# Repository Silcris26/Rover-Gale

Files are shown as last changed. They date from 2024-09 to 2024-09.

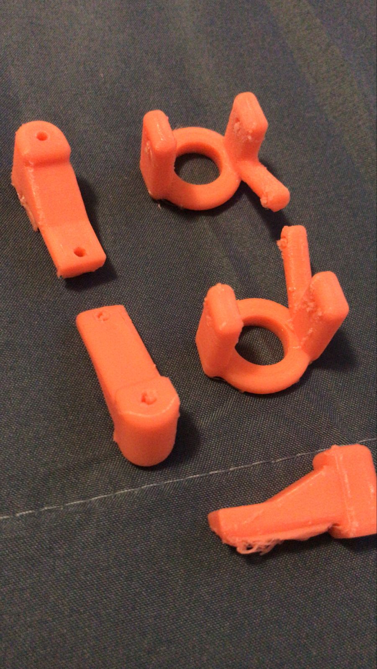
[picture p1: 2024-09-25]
Diseño 3D/6.jpg

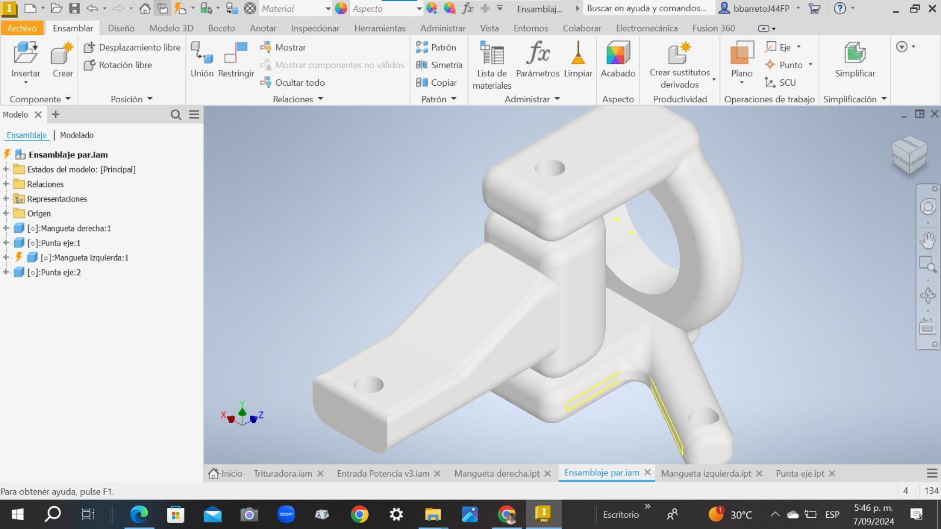
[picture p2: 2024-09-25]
Diseño 3D/3.jpg

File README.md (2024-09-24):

# Rover-Gale

A lo largo de los años, la exploración de Marte ha sido un desafío debido a las condiciones inhóspitas y la lejanía del planeta, las misiones tripuladas aún son extremadamente costosas y peligrosas, aún más cuando hablamos del análisis de la corteza marciana, lo que limita la capacidad de intervención humana para llevar a cabo investigaciones directas en su superficie. Esta problemática requiere de soluciones tecnológicas capaces de explorar, analizar y transmitir información desde Marte, la manera más práctica de hacerlo es a través de un Rover fácil de controlar y capaz de explorar el terreno hostil, lugares de complicado alcance y recorrer largas distancias. Se propone la implementación de motorreductores para las llantas traseras y un servomotor capaz de dar la dirección en las llantas delanteras con piezas impresas en 3D para su fácil replicación y reemplazo en caso de averías, su fuente de energía se da a través de baterías recargables lo cual no solo prolonga la vida útil del vehículo sino que también reduce significativamente la contaminación emitida, como resultado tenemos un Rover cuyas características le hacen eficiente, impulsando la comprensión científica y la preparación para misiones humanas en Marte, validado mediante pruebas hechas en terrenos similares.

Banner Envio Gratis Moderno Negro y Azul

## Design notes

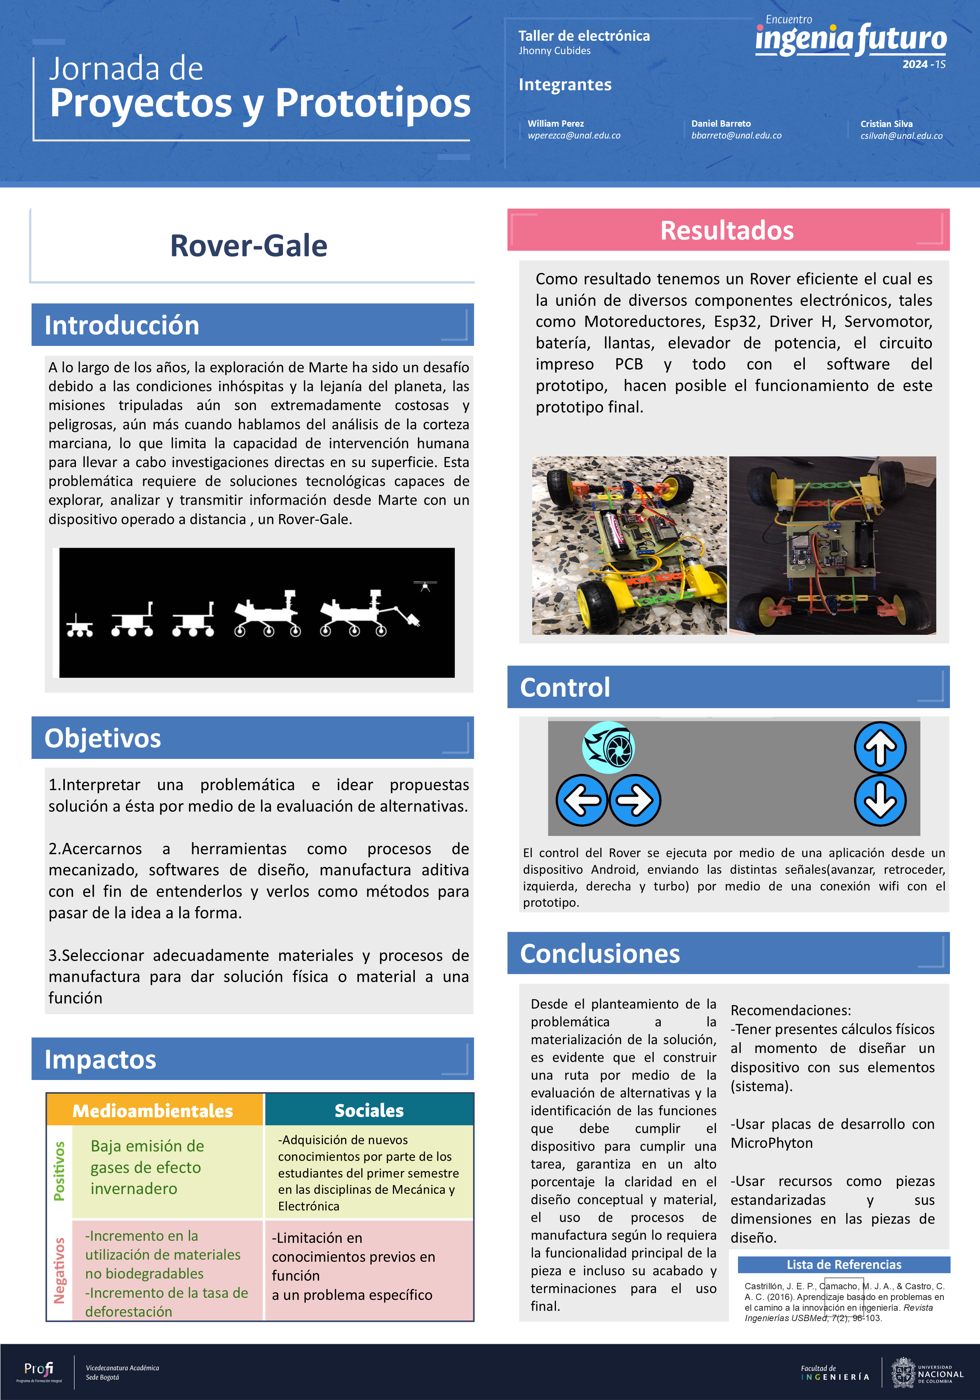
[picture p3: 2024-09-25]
Poster.png

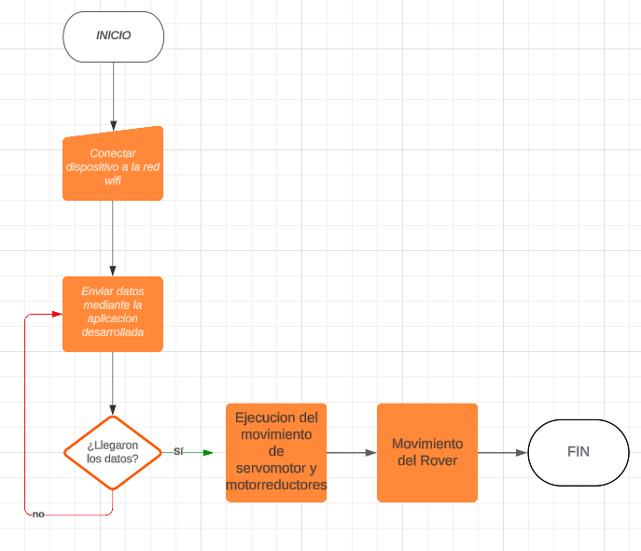
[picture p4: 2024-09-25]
Diagramas/Diagrama General.png

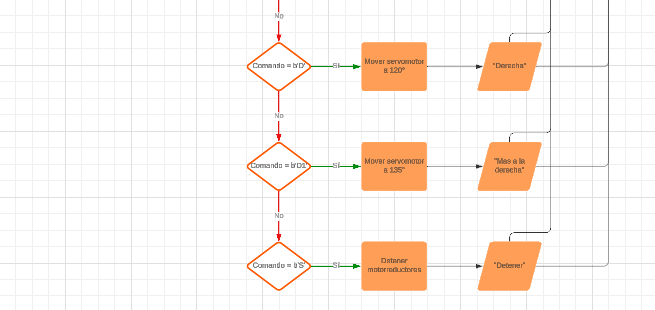
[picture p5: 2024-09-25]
Diagramas/SePartDiagrama.png

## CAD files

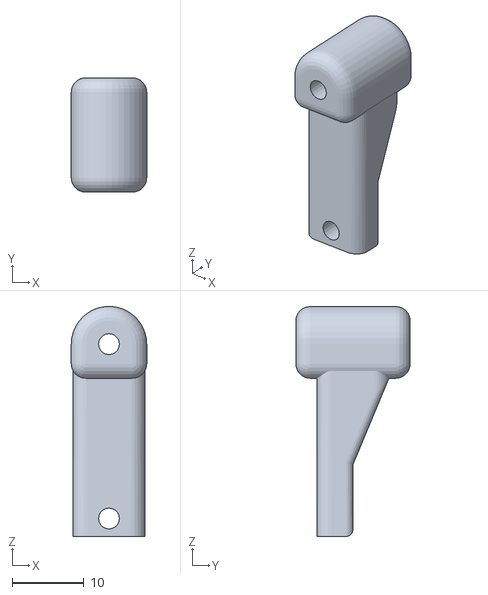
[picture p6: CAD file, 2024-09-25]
Diseño 3D/Punta eje.stl
10.5 x 15.9 x 32.0

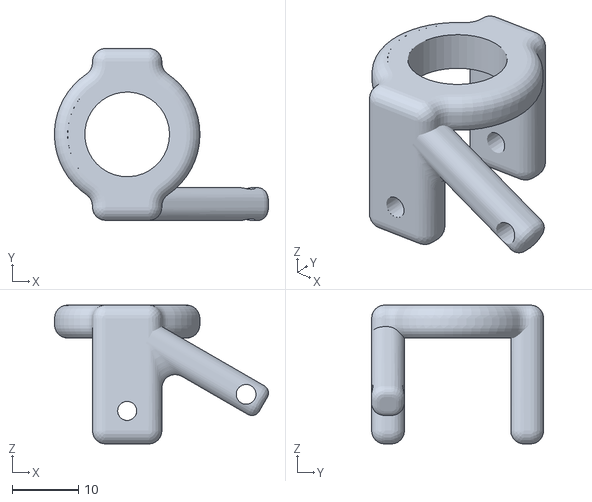
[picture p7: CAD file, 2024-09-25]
Diseño 3D/Mangueta izquierda.stl
32.3 x 26.0 x 21.0

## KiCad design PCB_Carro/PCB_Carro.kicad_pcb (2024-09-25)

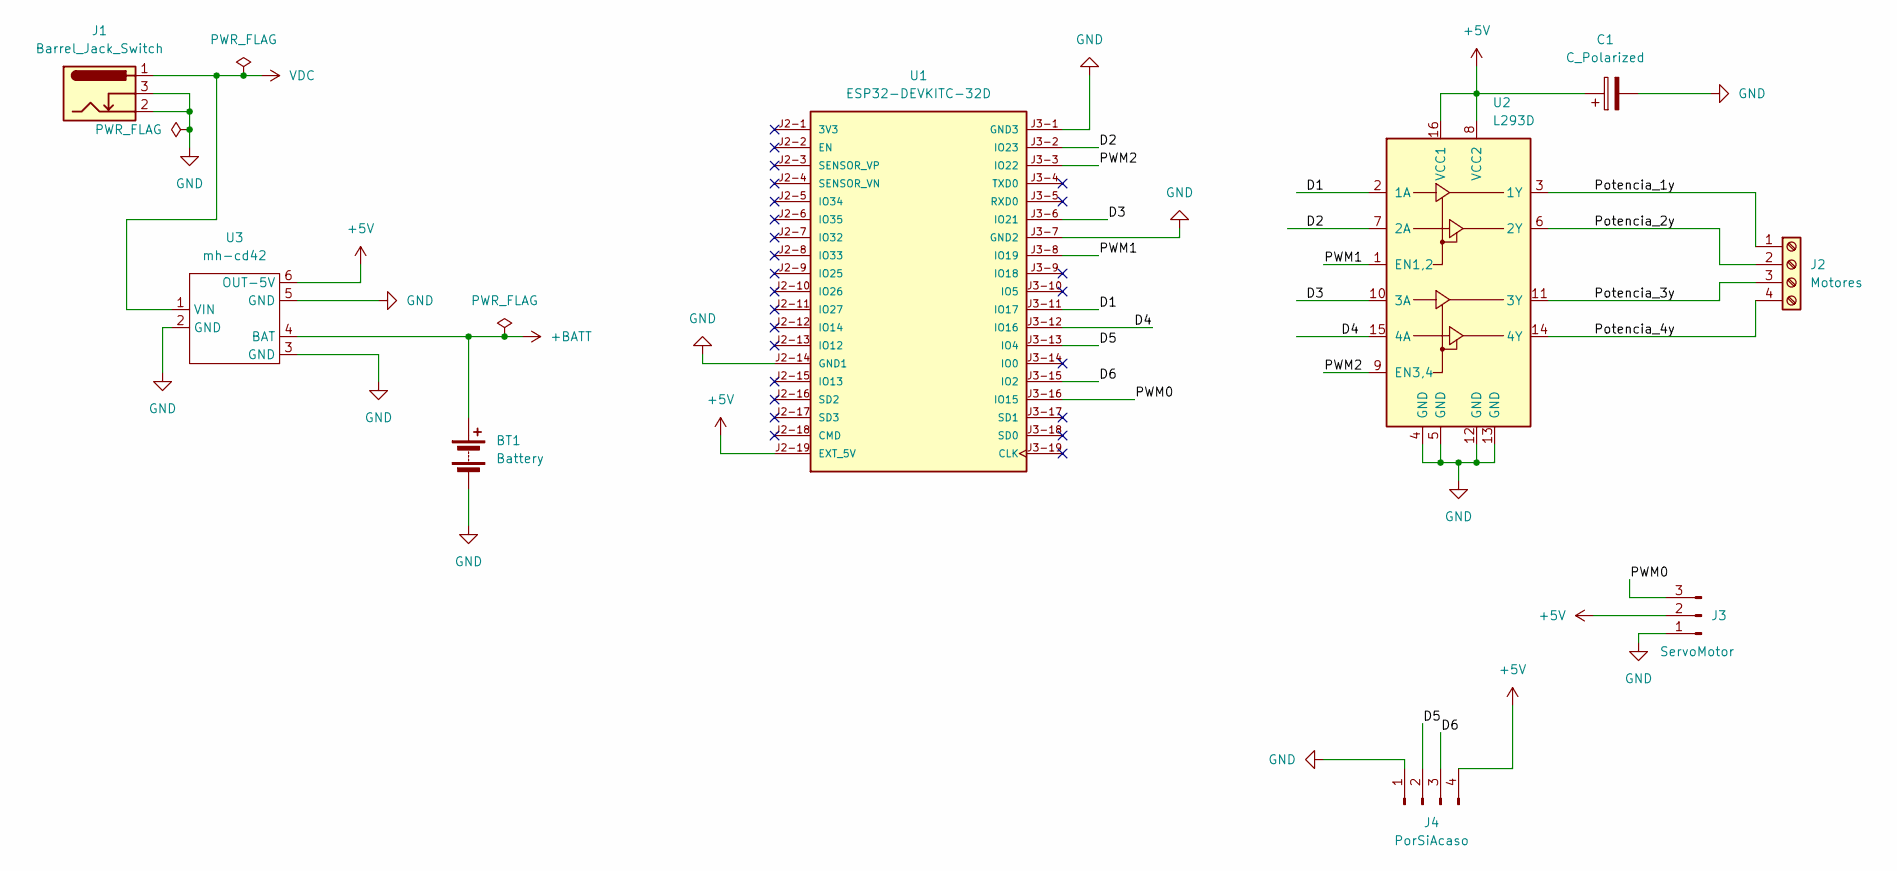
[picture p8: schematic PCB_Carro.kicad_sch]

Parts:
BT1: Battery; BatteryHolder_Keystone_1042_1x18650
C1: C_Polarized; CP_Radial_D5.0mm_P2.00mm
J1: Barrel_Jack_Switch; BarrelJack_Horizontal
J2: Motores; TerminalBlock_bornier-4_P5.08mm
J3: ServoMotor; PinHeader_1x03_P2.54mm_Vertical
J4: PorSiAcaso; PinHeader_1x04_P2.54mm_Vertical
U1: ESP32-DEVKITC-32D; MODULE_ESP32-DEVKITC-32D; PARTREV V4; DigiKey_Part_Number 4166-ESP32-DEVKITC-32D-ND
U2: L293D; DIP-16_W7.62mm
U3: mh-cd42

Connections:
+5V: C1.1, J3.2, J4.4, U1.J2-19 (EXT_5V), U2.8 (VCC2), U2.16 (VCC1), U3.6 (OUT-5V)
+BATT: BT1.1 (+), U3.4 (BAT)
/D1: U1.J3-11 (IO17), U2.2 (1A)
/D2: U1.J3-2 (IO23), U2.7 (2A)
/D3: U1.J3-6 (IO21), U2.10 (3A)
/D4: U1.J3-12 (IO16), U2.15 (4A)
/D5: J4.2, U1.J3-13 (IO4)
/D6: J4.3, U1.J3-15 (IO2)
/PWM0: J3.3, U1.J3-16 (IO15)
/PWM1: U1.J3-8 (IO19), U2.1 (EN1,2)
/PWM2: U1.J3-3 (IO22), U2.9 (EN3,4)
/Potencia_1y: J2.1, U2.3 (1Y)
/Potencia_2y: J2.2, U2.6 (2Y)
/Potencia_3y: J2.3, U2.11 (3Y)
/Potencia_4y: J2.4, U2.14 (4Y)
GND: BT1.2 (-), C1.2, J1.2, J1.3, J3.1, J4.1, U1.J2-14 (GND1), U1.J3-1 (GND3), U1.J3-7 (GND2), U2.4 (GND), U2.5 (GND), U2.12 (GND), U2.13 (GND), U3.2 (GND), U3.3 (GND), U3.5 (GND)
VDC: J1.1, U3.1 (VIN)

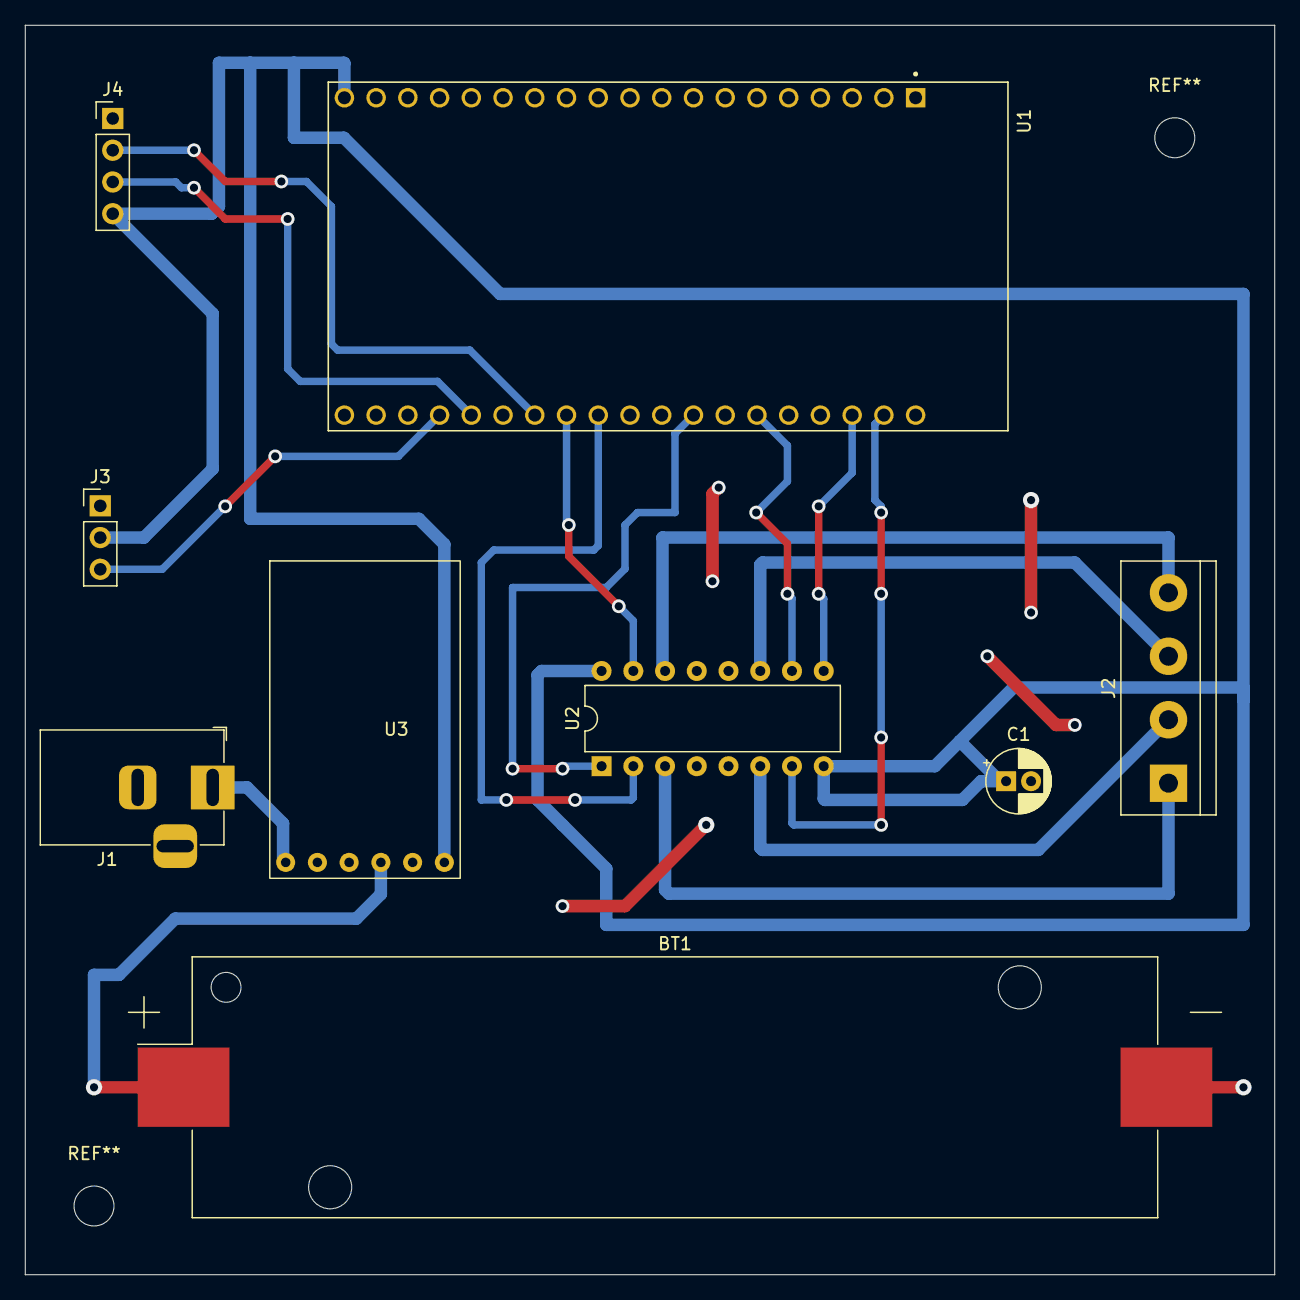
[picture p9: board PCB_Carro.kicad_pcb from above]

Board: 2 copper layers, 100.0 x 100.0 mm, 9 parts (0 on the bottom side), 17 nets.

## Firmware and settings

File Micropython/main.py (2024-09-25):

# import usocket as socket
import socket
from machine import Pin, PWM
import time



# Configura los pines 
izqin1 = Pin(17, Pin.OUT)
izqin2 = Pin(23, Pin.OUT)
izqvel = PWM(Pin(19), freq=1000, duty=512)  # 50% del ciclo de trabajo
derin1 = Pin(21, Pin.OUT)
derin2 = Pin(16, Pin.OUT)
dervel = PWM(Pin(22), freq=1000, duty=512)  # 50% del ciclo de trabajo
servo_pin = Pin(15)
servo = PWM(servo_pin, freq=50)

    
# Agregar nport de donde está el servidor TCP, en el ejemplo: 3000
serverAddressPort = socket.getaddrinfo('0.0.0.0', 3000)[0][-1]
# Cantidad de bytes a recibir
bufferSize  = 128

# Descomentar si el esp32 será una estación
#from wifiSTA import connectSTA as connect

# Descomentar si el esp32 estará en modo de acceso AP
from wifiAP1 import apConfig as connect

# poner acá el nombre de red ssid y password para conectarse
connect("RoverGale","87654321",3)

# Función 
def exec(data):
    print(data)
    if data == b'A':
        izqin1.on()
        izqin2.off()
        derin1.on()
        derin2.off()
        print("Adelante")
    elif data == b'T':
        izqvel.duty(1023)
        dervel.duty(1023)
        print("Turbo")
    elif data == b'ST':
        izqvel.duty(512)
        dervel.duty(512)
        print("Detener turbo")
    elif data == b'B':
        izqin1.off()
        izqin2.on()
        derin1.off()
        derin2.on()
        print("Atras")
    elif data == b'C':
        mover_servo(60)
        print("Izquierda")
    elif data == b'C1':
        mover_servo(45)
        print("Mas a la izquierda")
    elif data == b'D':
        mover_servo(120)
        print("Derecha")
    elif data == b'D1':
        mover_servo(135)
        print("Mas a la derecha")
    elif data == b'S': 
        izqin1.off()
        izqin2.off()
        derin1.off()
        derin2.off()
        print("Detener")
    elif data == b'E':
        mover_servo(90)
        print("Llantas centradas")
    else:
        print("Otra opcion")
        
def mover_servo(angulo):
    # Convierte el ángulo a un ciclo de trabajo PWM
    # 0° -> 2.5% (40) y 180° -> 12.5% (120)
    duty = int(40 + (angulo / 180) * 80)  # Mapea el ángulo a duty
    servo.duty(duty)
    
sk = socket.socket()
sk.bind(serverAddressPort)
sk.listen(1)
print("Listening on: ", serverAddressPort)

while True:
    conn, addr = sk.accept()
    while True:
        data = conn.recv(bufferSize)
        # Si dato fue recibido, se decide que hacer con el.
        if data:
            exec(data)
            # Con la siguiente instruccion se pueden enviar datos al
            # dispositivo conectado
            conn.sendall("ok")
            #conn.send("ok")
    conn.close()

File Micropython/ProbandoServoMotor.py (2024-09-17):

from machine import Pin, PWM
import time

# Configuración del servomotor
servo_pin = Pin(15)  # Pin de control del servomotor
servo = PWM(servo_pin, freq=50)  # Frecuencia de 50 Hz

def set_angulo(angulo):
    # Convertir el ángulo a un ciclo de trabajo
    duty = int((angulo / 180) * 102 + 26) 
    servo.duty(duty)

try:
    while True:
        # Mover el servomotor a 0 grados
        set_angulo(0)
        time.sleep(1)
        
        # Mover el servomotor a 90 grados
        set_angulo(90)
        time.sleep(1)
        
        # Mover el servomotor a 180 grados
        set_angulo(180)
        time.sleep(1)

except KeyboardInterrupt:
    # Detener el servomotor
    servo.duty(0)
    print("Programa terminado")

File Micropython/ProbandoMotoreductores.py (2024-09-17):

from machine import Pin
import time

# Definimos los pines de control del puente H
motor1_in1 = Pin(17, Pin.OUT)  # Control Motor 1
motor1_in2 = Pin(23, Pin.OUT)  # Control Motor 1
motor2_in1 = Pin(21, Pin.OUT)  # Control Motor 2
motor2_in2 = Pin(16, Pin.OUT)  # Control Motor 2

def motor1_adelante():
    motor1_in1.value(1)
    motor1_in2.value(0)

def motor1_atras():
    motor1_in1.value(0)
    motor1_in2.value(1)

def motor2_adelante():
    motor2_in1.value(1)
    motor2_in2.value(0)

def motor2_atras():
    motor2_in1.value(0)
    motor2_in2.value(1)

def detener_motores():
    motor1_in1.value(0)
    motor1_in2.value(0)
    motor2_in1.value(0)
    motor2_in2.value(0)

while True:
    motor1_adelante()
    motor2_adelante()
    time.sleep(2)  # Ambos motores hacia adelante
    
    detener_motores()
    time.sleep(2)  # Parar

    motor1_adelante()
    motor2_atras()
    time.sleep(2)  # Ambos motores hacia atrás
    
    detener_motores()
    time.sleep(2)  # Parar
